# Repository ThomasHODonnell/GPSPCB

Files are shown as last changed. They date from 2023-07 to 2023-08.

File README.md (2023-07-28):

# GPS PCB - designing a consumer electronic from start to finish

## *Concepts*
- My father run a bicycle shop. Some of his customers' bicycles have been stolen. He asked me if I could design a product to help combat this problem. This problem led me to a GPS based solution - to get things started. 
- The solution provided here is an embedded system that can transmit its location upon request utilizing a satallite HTTP request API.
- This product combats the problem by not only locating a stolen / lost bicycle, but my locating a potential thief. Therefore, this product can act as a form of location verification for law enforcement bodies in pursuit of any item this PCB is attached to. 

## *Logistics* 
- I have designed 3D printed CAD models to safely secure this system on a moving bicycle. This system comfortably holds the PCB, its components and a battery. 
- While I have not completed suffient testing to determine the battery life of this system, its power consumption is very low for a reasonably sized battery and its capacity. This combination should ensure that the device does not need to be recharged for a reasonable amount of time. 

## Technical Information
- This initial design is intended to be minimalistic. I have foregone a Microcontroller Unit in an effort to minimize power consumption, size, and cost. Alternativly, I have implemented a standalone Reciever / Transciever combination to complete the necessary funcitonality without any additional computing. 
- Of course, there are a number of other ICs to accompany these functional components, such as LDO Regulators, Operational Amplifiers, Logic Gates, Switches, Battery IC, Low Noise Amplifier, and Antennas.  
- While this Electronic Circuit requires significantly more testing, the technical aspectrs of this solution offer a helpful initial solution to a logicically challenging problem. 

## Disclaimer
- I am a third-year Computer Engineering Student. In no fashion am I qualified to develop professional grade products at this point in my career. 
- Therefore, I would not recommend using any of my design choices for other applications without inquiring a professional. 
- I will post other README files within other folders with other information, screenshots, and files.

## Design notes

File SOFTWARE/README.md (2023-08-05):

# Software Information
 
## JSON

- The files found in this folder contain outline templates provided by STM for a JSON request and response. 
- These files have yet to be filled with server / device information. 
- Firmware will be developed to transmit / recieve these files.

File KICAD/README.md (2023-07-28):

# Kicad Files

## *This folder contains files needed to open / edit this project in KICAD.* 

- I'll use these files to provide screenshots from the IMAGES folder for your entertainment!
- This file could also be considered as a BOM, but i'll leave out component prices as they fluctuate frequently. 
- The PCB should be finished with production within the next week or so (7/27/23), after which I will upload real images of the device.

### **Electrical Schematics** 

#### Complete Schematic
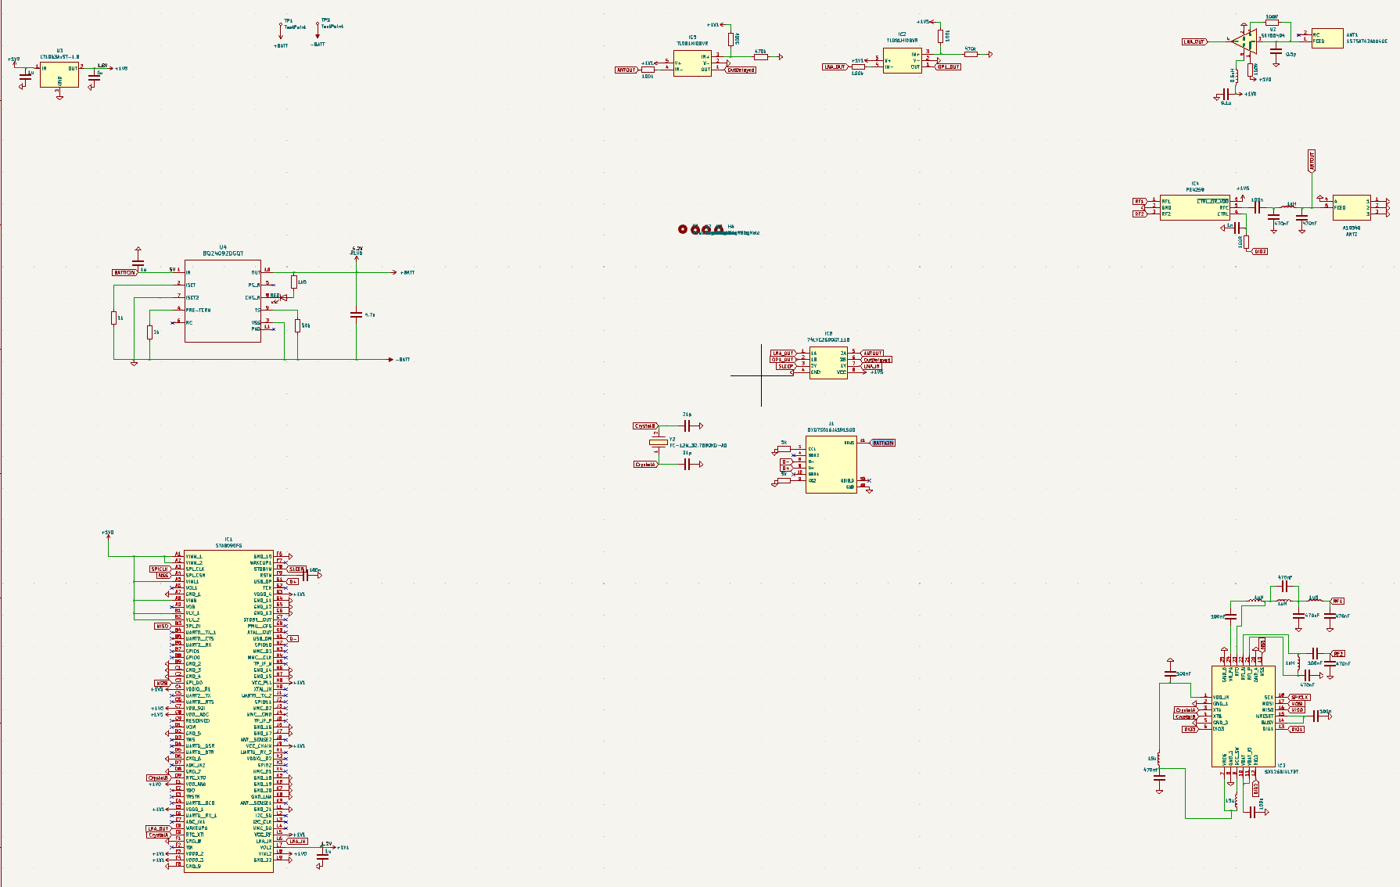
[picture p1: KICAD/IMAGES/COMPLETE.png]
Complete Schematic


#### LDO and Battery IC
- LDO(1.8V): LT1963A - Linear Technology
-  Rechargable Battert IC: BQ24092 - T.I.
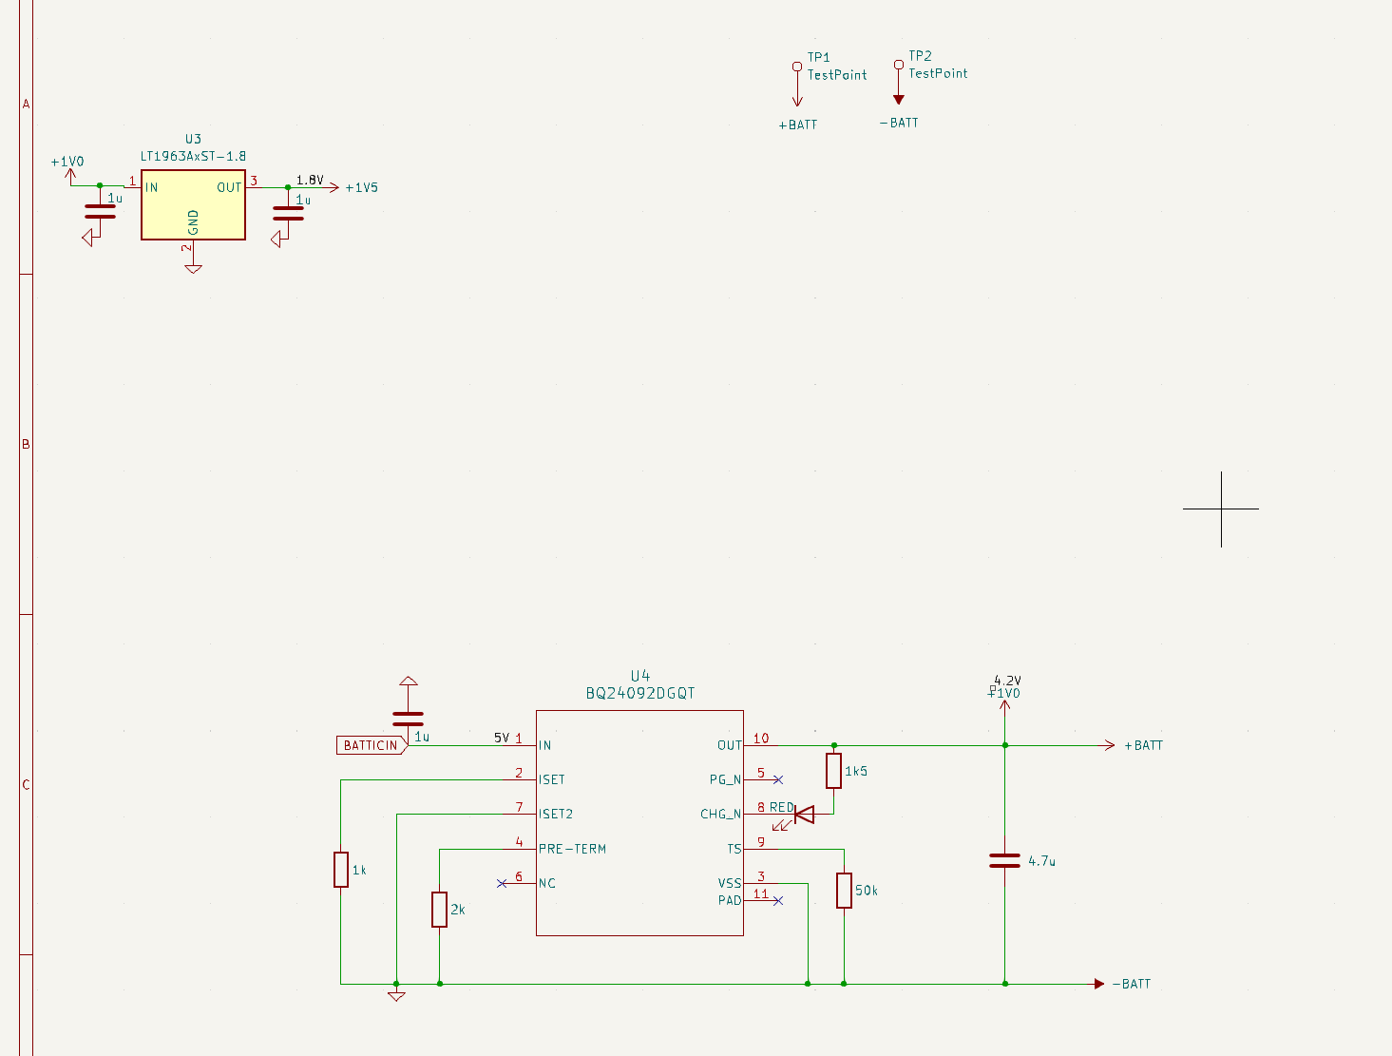
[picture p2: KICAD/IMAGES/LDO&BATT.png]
LDO + BATT ICS


#### Reciever
- RF Reciever: STA8090FG - STM32MicroElectronics
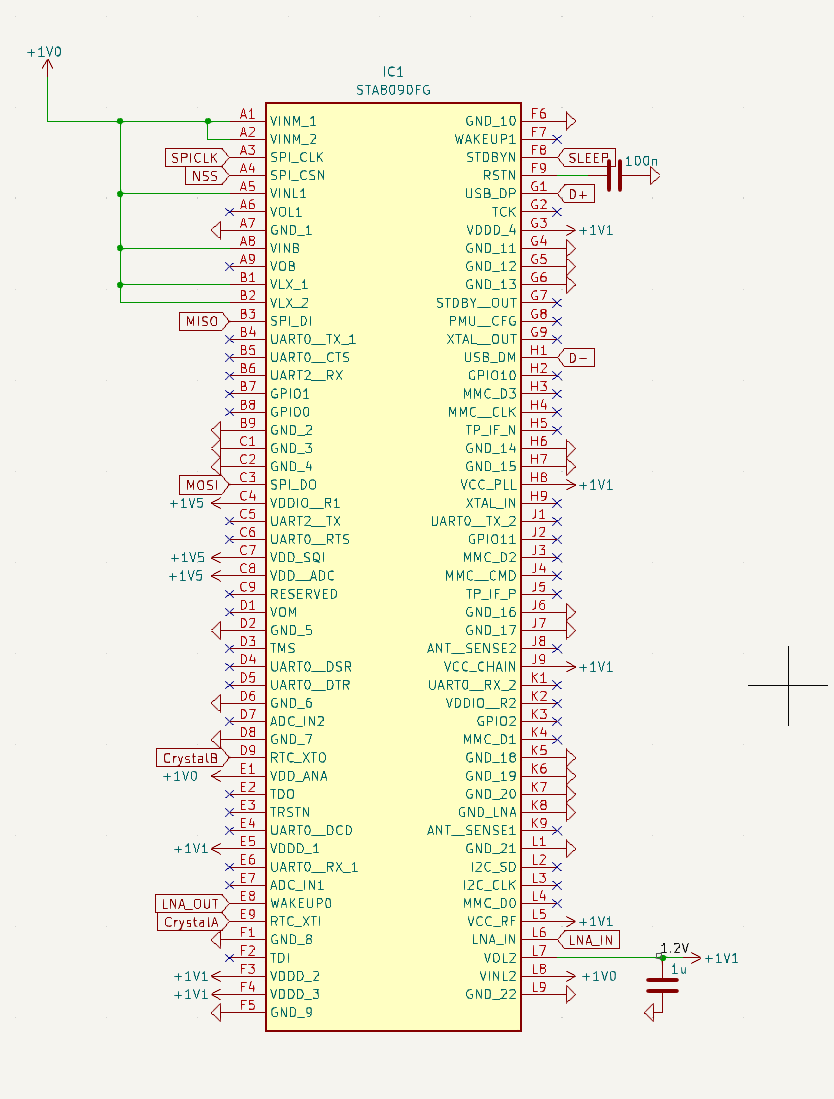
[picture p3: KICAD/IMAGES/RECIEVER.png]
RECIEVER
- 

#### Transciever
- RF signal transciever: SX1268IMLTRT - Semtech Corp. 
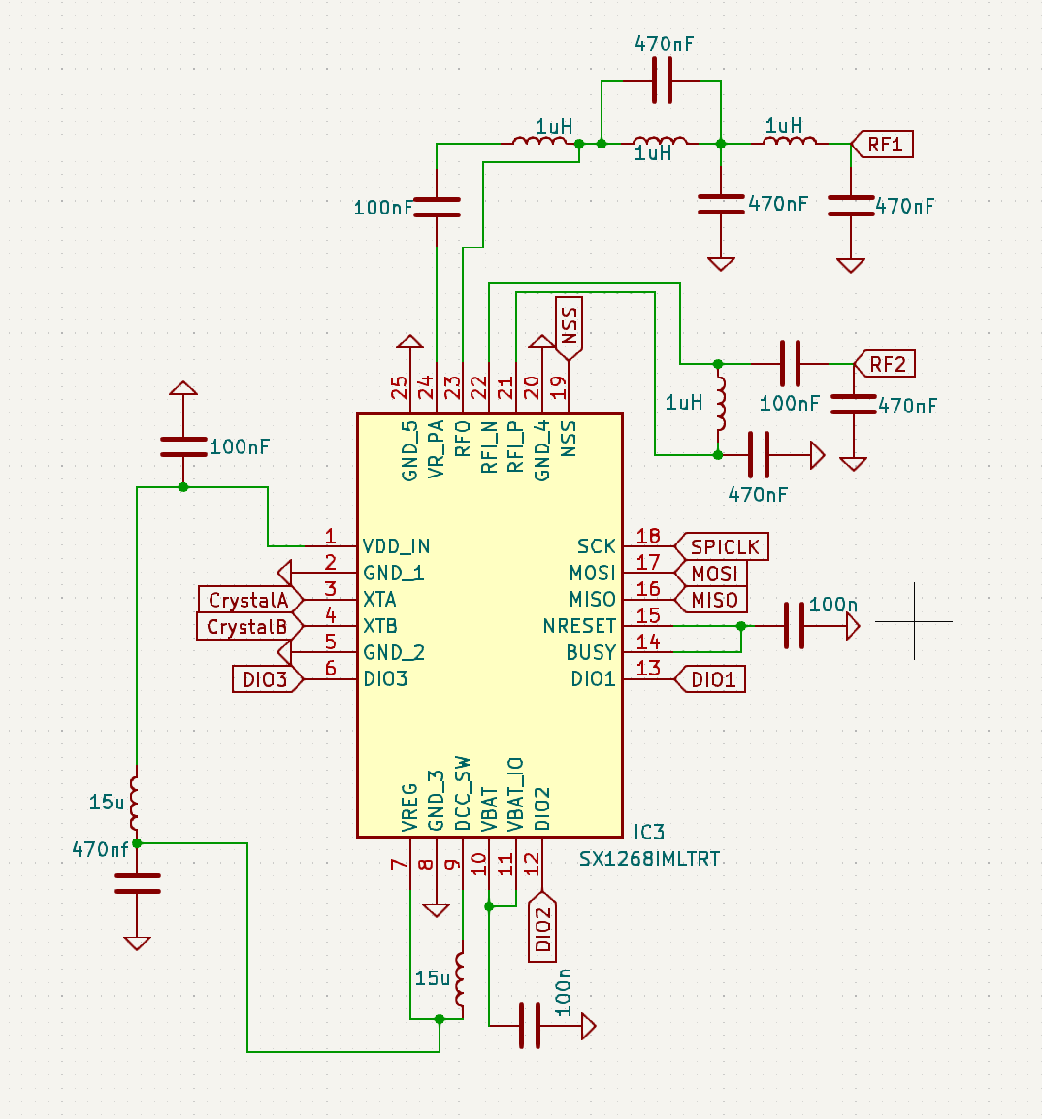
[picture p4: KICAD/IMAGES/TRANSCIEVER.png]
TRANSCIEVER


#### Various Components
- Op-Amp: TL081HIDBVR - T.I.
- LNA: SKY65404-31 - Skyworks
- Input Antenna: 1575AT43A0040001E - Johanson
- SPDT RF Switch: PE4259 - Pasternack
- Output Antenna: A10340 - Antenova
- Dual NAND Gate: 74LVC2G00GT,115 - Nexperia
- Water Resistant USBC Port: DX07S016JA1R1500 - JAE Elec. 
- 32 MHZ Crystal: FC-12M 32.7680KD-A0 - EPSON

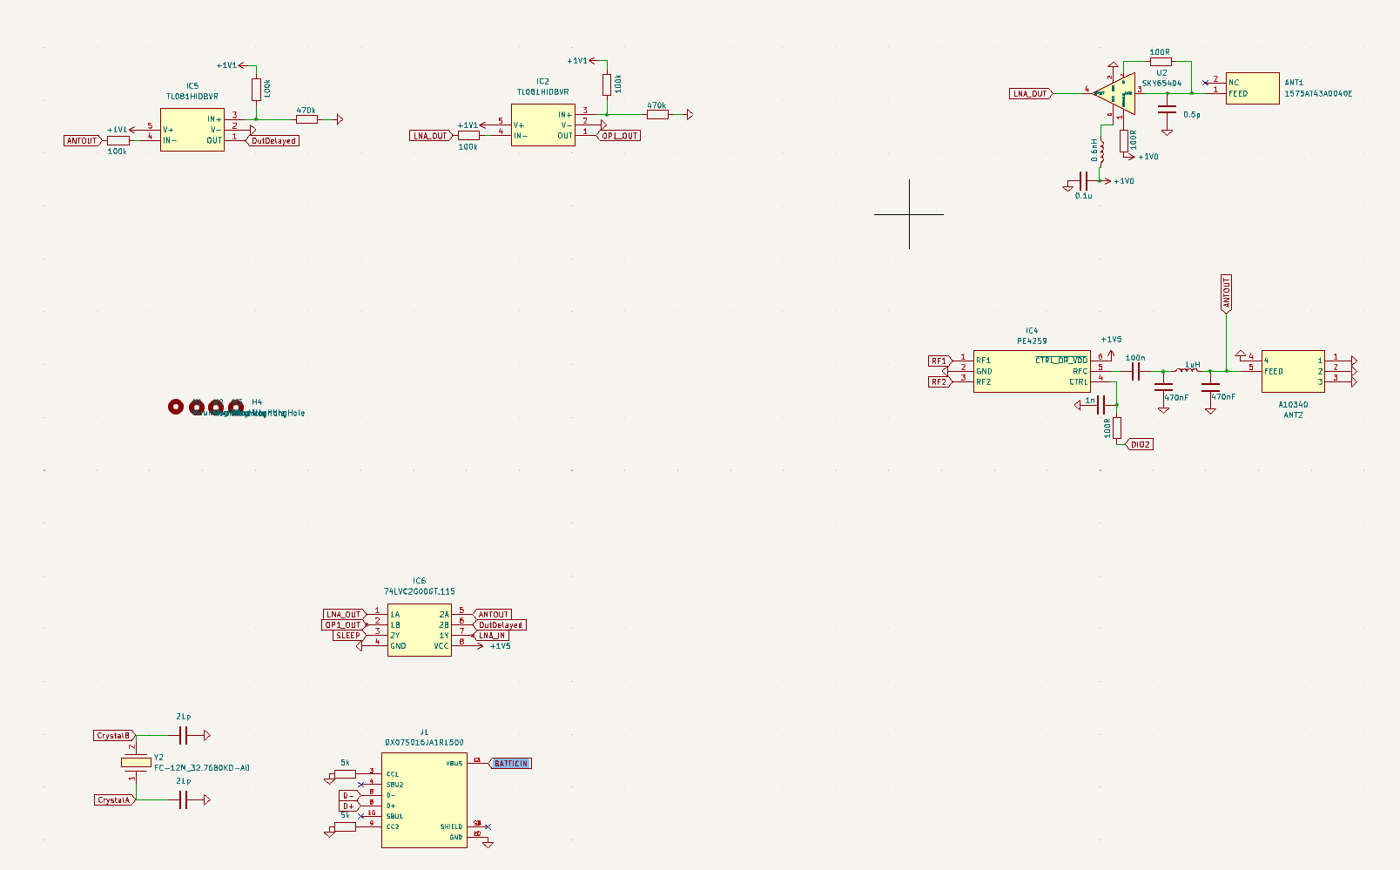
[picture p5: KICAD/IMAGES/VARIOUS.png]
VARIOUS


### **PCB Schematics**
- I will only show a screenshot of the Front Copper layer, as all of the components are located on this layer. 
- If interested, I welcome a detailed review of the PCB design through the direct file found in this folder. 
- DISCLAIMER: I AM NOT EMPLOYED BY PROTECTION AUTOMATED. I am interested in entrepreneurship in the future. 
If testing proves that a version of this product could become viable, I wanted to label the project as that businesses prototype. 

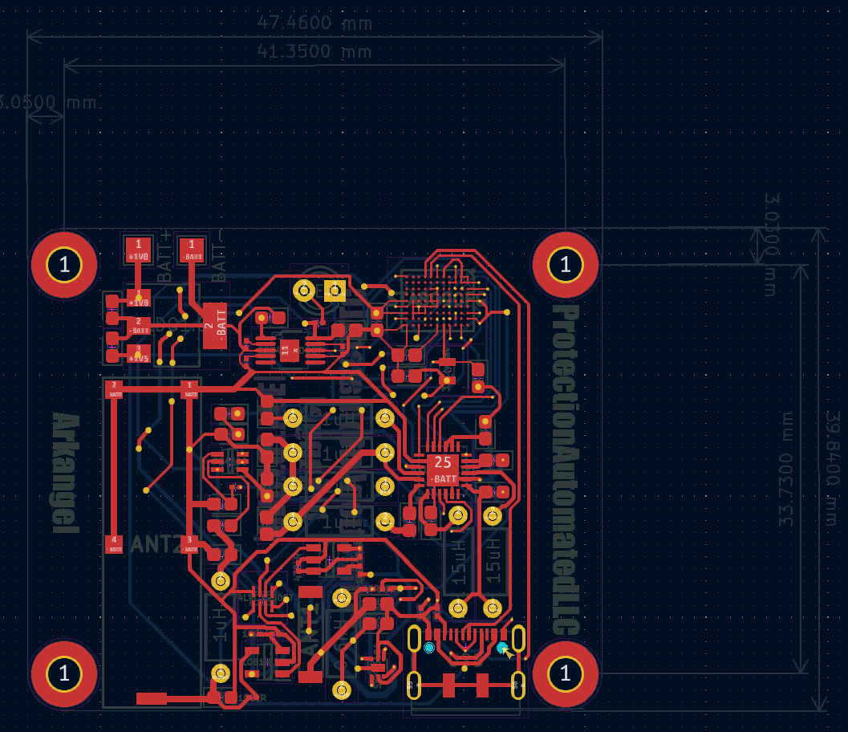
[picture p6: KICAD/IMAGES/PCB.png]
Front Copper Layer


- A 3D view for a more clear image. 

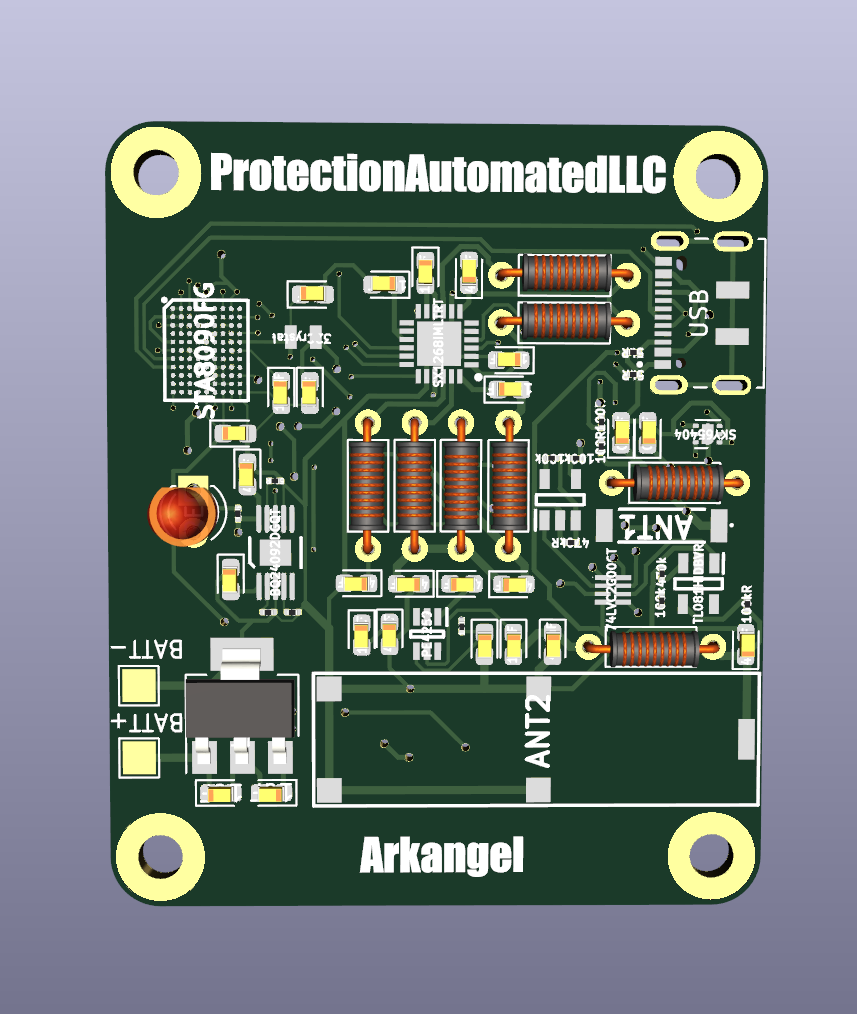
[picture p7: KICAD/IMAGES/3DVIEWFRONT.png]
Front 3D View

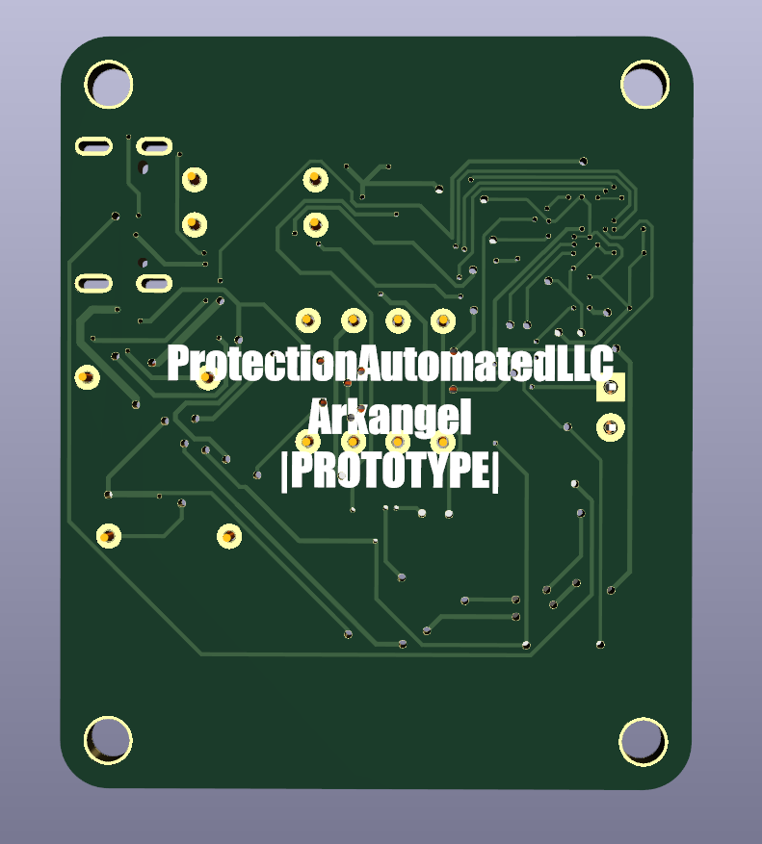
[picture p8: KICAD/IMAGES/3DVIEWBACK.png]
Rear 3D View


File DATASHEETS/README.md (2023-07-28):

# Datasheets 

- This file contains all of the datasheets for components in this file. 
- I based the vast majority of my design decisions on information found in these files. 
- In addition, there may be datasheets of additional parts not used in the design. 
  - When facing the component selection stage, I downloaded component datasheets that I suspected may be of use to me. 
  - Not all of these components are used, but I found their datasheets to provide helpful context information for similar parts I used. 
  - So, I kept them here for future reference.

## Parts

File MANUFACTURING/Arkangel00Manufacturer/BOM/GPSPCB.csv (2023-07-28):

Id | Designator | Footprint | Quantity | Designation | Supplier and ref
1 | C11,C15,C6,C11,C7 | CP_EIA-1608-08_AVX-J | 5 | 1u
2 | C21,C19,C25,C13,C20,C26,C23 | CP_EIA-1608-08_AVX-J | 7 | 470nF
3 | R9,R14,R15,R11 | R_0201_0603Metric | 4 | 100k
4 | C22,C18,C16 | CP_EIA-1608-08_AVX-J | 3 | 100nF
5 | C24,C12 | CP_EIA-1608-08_AVX-J | 2 | 100n
6 | C10,C10 | CP_EIA-1608-08_AVX-J | 2 | 4.7u
7 | H2,H1,H4,H3 | MountingHole_2.1mm | 4 | MountingHole
8 | ANT1 | 1575AT43A0040E | 1 | 1575AT43A0040E
9 | L5,L2,L7,L8,L6 | L_Axial_L5.3mm_D2.2mm_P7.62mm_Horizontal_Vishay_IM-1 | 5 | 1uH
10 | U3 | SOT-223-3_TabPin2 | 1 | LT1963AxST-1.8
11 | R2,R8 | R_0201_0603Metric | 2 | 5k
12 | R6 | R_0201_0603Metric | 1 | 50k
13 | R16,R10 | R_0201_0603Metric | 2 | 470k
14 | R1,R3,R12 | R_0201_0603Metric | 3 | 100R
15 | C14 | CP_EIA-1608-08_AVX-J | 1 | 470nf
16 | D2 | LED_D3.0mm | 1 | RED
17 | C4,C5 | CP_EIA-1608-08_AVX-J | 2 | 21p
18 | L3,L4 | L_Axial_L5.3mm_D2.2mm_P7.62mm_Horizontal_Vishay_IM-1 | 2 | 15uH
19 | C9,C9 | CP_EIA-1608-08_AVX-J | 2 | 0.5p
20 | C27 | CP_EIA-1608-08_AVX-J | 1 | 1n
21 | R4 | R_0201_0603Metric | 1 | 1k
22 | U2 | Skyworks_SKY65404-31 | 1 | SKY65404
23 | IC6 | 74AVC9112GTX | 1 | 74LVC2G00
24 | IC5,IC2 | SOT95P280X145-5N | 2 | TL081HIDBVR
25 | ANT2 | A10340 | 1 | A10340
26 | IC3 | QFN50P400X400X100-25N-D | 1 | SX1268
27 | J1 | JAE_DX07S016JA1R1500 | 1 | DX07S016JA1R1500
28 | C8,C8 | CP_EIA-1608-08_AVX-J | 2 | 0.1u
29 | TP | TestPoint_Pad_2.0x2.0mm | 1 | BATT+
30 | C1,C17 | CP_EIA-1608-08_AVX-J | 2 | 100nf
31 | Y2 | FC12M327680KDA0 | 1 | Crystal
32 | TP2 | TestPoint_Pad_2.0x2.0mm | 1 | BATT-
33 | R7 | R_0201_0603Metric | 1 | 1k5
34 | U4 | DGQ0010D_NV_N | 1 | BQ24092
35 | R5 | R_0201_0603Metric | 1 | 2k
36 | STA8090FG | BGA99C50P9X11_500X600X120 | 1 | STA8090FG
37 | IC4 | SOT65P210X110-6N | 1 | PE4259
38 | L1 | L_Axial_L5.3mm_D2.2mm_P7.62mm_Horizontal_Vishay_IM-1 | 1 | 0.6nH

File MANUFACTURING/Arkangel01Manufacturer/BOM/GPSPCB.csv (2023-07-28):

Id | Designator | Footprint | Quantity | Designation | Supplier and ref
1 | C14,C19,C23,C21,C25,C13,C26,C20 | CP_EIA-1608-08_AVX-J | 8 | 470nF
2 | C9 | CP_EIA-1608-08_AVX-J | 1 | 0.5pF
3 | R5 | R_0201_0603Metric | 1 | 2k
4 | L3,L4 | L_Axial_L5.3mm_D2.2mm_P7.62mm_Horizontal_Vishay_IM-1 | 2 | 15uH
5 | C18,C16,C12,C22,C24,Ce,C17 | CP_EIA-1608-08_AVX-J | 7 | 100nF
6 | C15,C6,C7,C11 | CP_EIA-1608-08_AVX-J | 4 | 1uF
7 | D2 | LED_D3.0mm | 1 | RED
8 | R14 | R_0201_0603Metric | 1 | 100kR
9 | H4,H2,H3,H1 | MountingHole_2.7mm_M2.5_Pad_TopOnly | 4 | MountingHole
10 | C4,C5 | CP_EIA-1608-08_AVX-J | 2 | 21pF
11 | J1 | JAE_DX07S016JA1R1500 | 1 | USB
12 | L2,Le,L7,L8,L5 | L_Axial_L5.3mm_D2.2mm_P7.62mm_Horizontal_Vishay_IM-1 | 5 | 1uH
13 | R9,R15,R11 | R_0201_0603Metric | 3 | 100k
14 | R4 | R_0201_0603Metric | 1 | 1k
15 | IC2,IC5 | SOT95P280X145-5N | 2 | TL081HIDBVR
16 | U4 | DGQ0010D_NV_N | 1 | BQ24092DGQT
17 | R7 | R_0201_0603Metric | 1 | 1k5
18 | IC4 | SOT65P210X110-6N | 1 | PE4259
19 | R6 | R_0201_0603Metric | 1 | 50kR
20 | TP2 | TestPoint_Pad_2.0x2.0mm | 1 | BATT-
21 | Y2 | FC12M327680KDA0 | 1 | 32Crystal
22 | ANT1 | 1575AT43A0040E | 1 | 1575AT43A0040E
23 | L1 | L_Axial_L5.3mm_D2.2mm_P7.62mm_Horizontal_Vishay_IM-1 | 1 | 0.6nH
24 | R16 | R_0201_0603Metric | 1 | 470k
25 | R10 | R_0201_0603Metric | 1 | 470kR
26 | ANT2 | A10340 | 1 | A10340
27 | R2,R8 | R_0201_0603Metric | 2 | 5kR
28 | U2 | Skyworks_SKY65404-31 | 1 | SKY65404
29 | C8 | CP_EIA-1608-08_AVX-J | 1 | 0.1uF
30 | U3 | SOT-223-3_TabPin2 | 1 | LDO1.8
31 | IC6 | 74AVC9112GTX | 1 | 74LVC2G00GT
32 | C10 | CP_EIA-1608-08_AVX-J | 1 | 4.7uF
33 | IC3 | QFN50P400X400X100-25N-D | 1 | SX1268IMLTRT
34 | IC1 | BGA99C50P9X11_500X600X120 | 1 | STA8090FG
35 | R3,R12,R1 | R_0201_0603Metric | 3 | 100R
36 | C27 | CP_EIA-1608-08_AVX-J | 1 | 1nF
37 | TP1 | TestPoint_Pad_2.0x2.0mm | 1 | BATT+

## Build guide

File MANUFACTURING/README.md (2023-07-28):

# Manufacturing Files

## *This folder contains all manufacturing files for both versions of this PCB.*
These files were sent directly to the manufacturer and can be viewed through Kicad's GERBER VIEWER software.

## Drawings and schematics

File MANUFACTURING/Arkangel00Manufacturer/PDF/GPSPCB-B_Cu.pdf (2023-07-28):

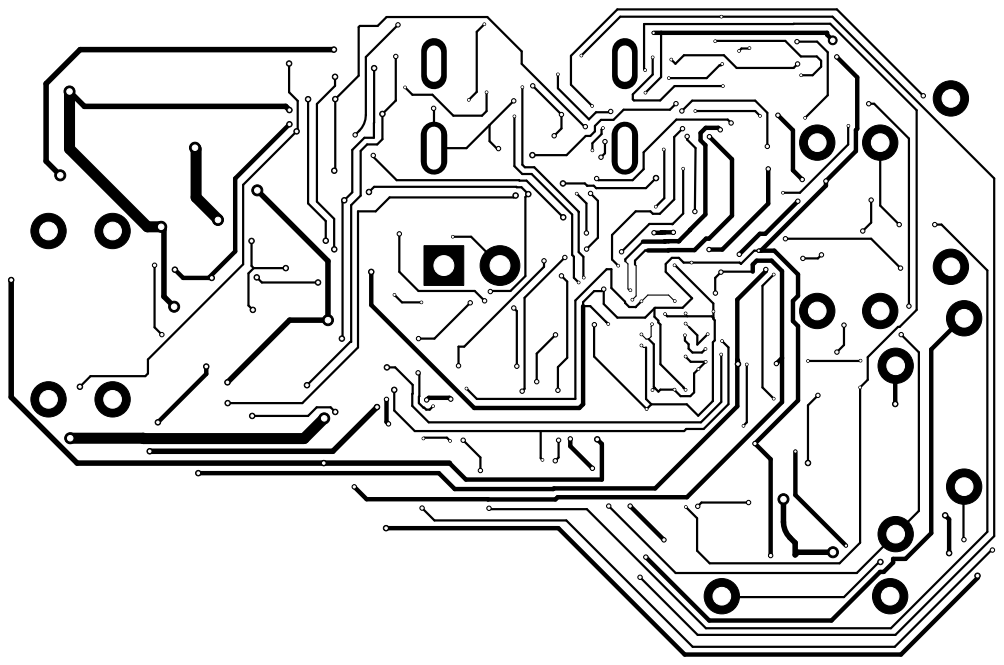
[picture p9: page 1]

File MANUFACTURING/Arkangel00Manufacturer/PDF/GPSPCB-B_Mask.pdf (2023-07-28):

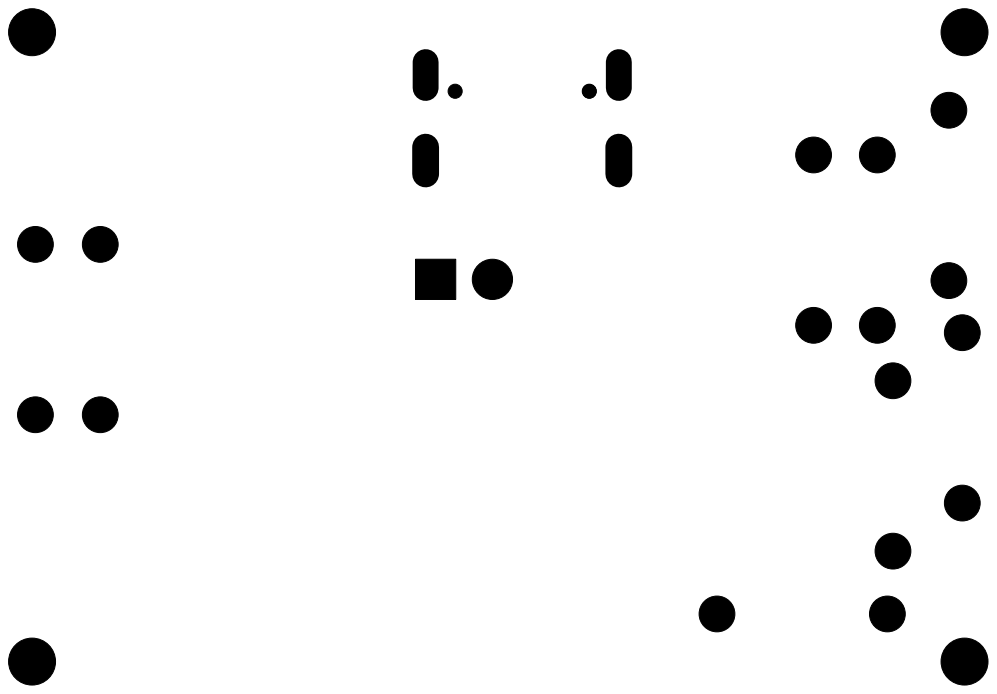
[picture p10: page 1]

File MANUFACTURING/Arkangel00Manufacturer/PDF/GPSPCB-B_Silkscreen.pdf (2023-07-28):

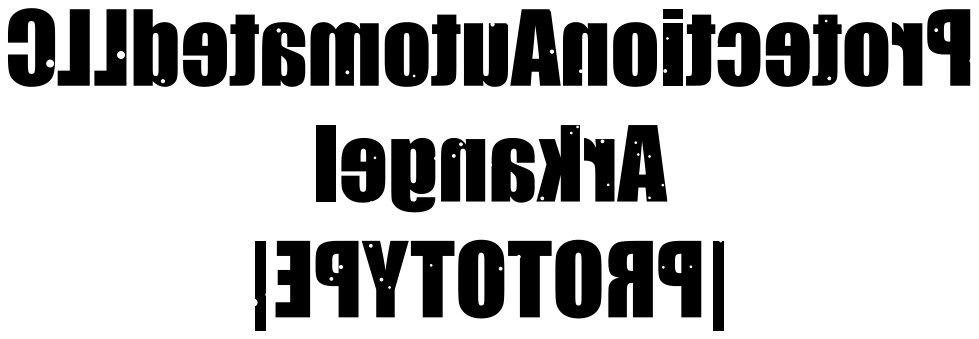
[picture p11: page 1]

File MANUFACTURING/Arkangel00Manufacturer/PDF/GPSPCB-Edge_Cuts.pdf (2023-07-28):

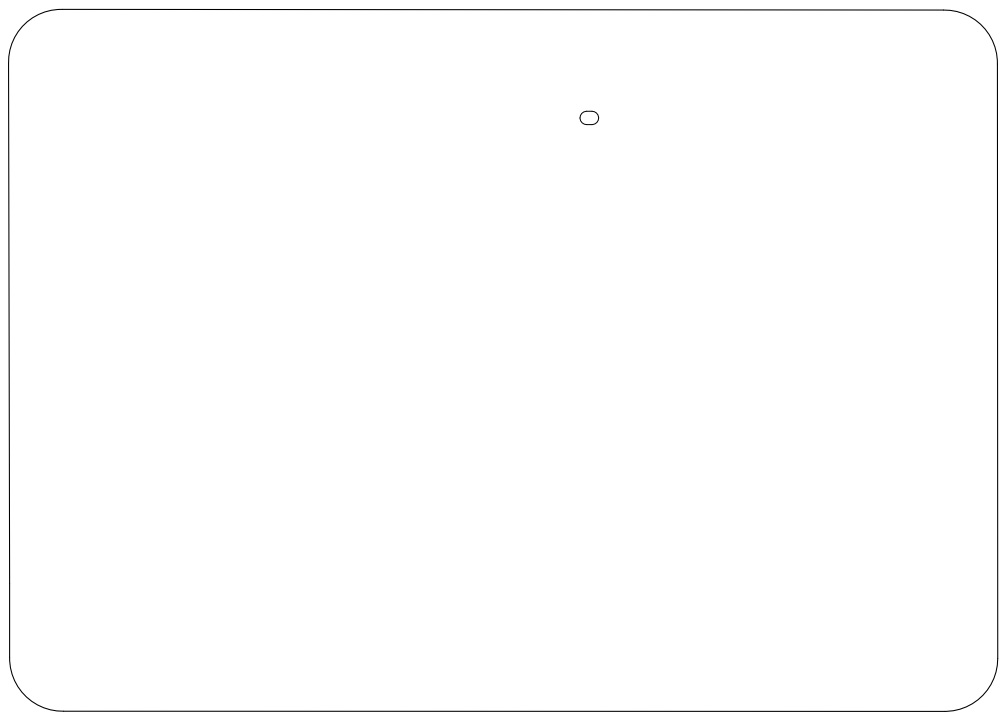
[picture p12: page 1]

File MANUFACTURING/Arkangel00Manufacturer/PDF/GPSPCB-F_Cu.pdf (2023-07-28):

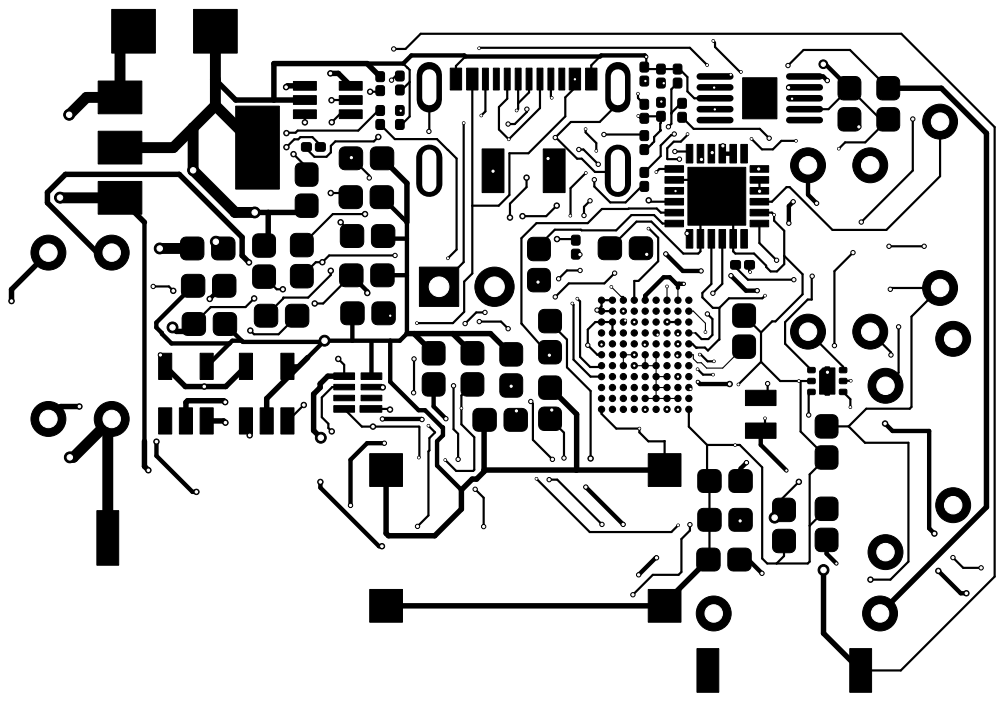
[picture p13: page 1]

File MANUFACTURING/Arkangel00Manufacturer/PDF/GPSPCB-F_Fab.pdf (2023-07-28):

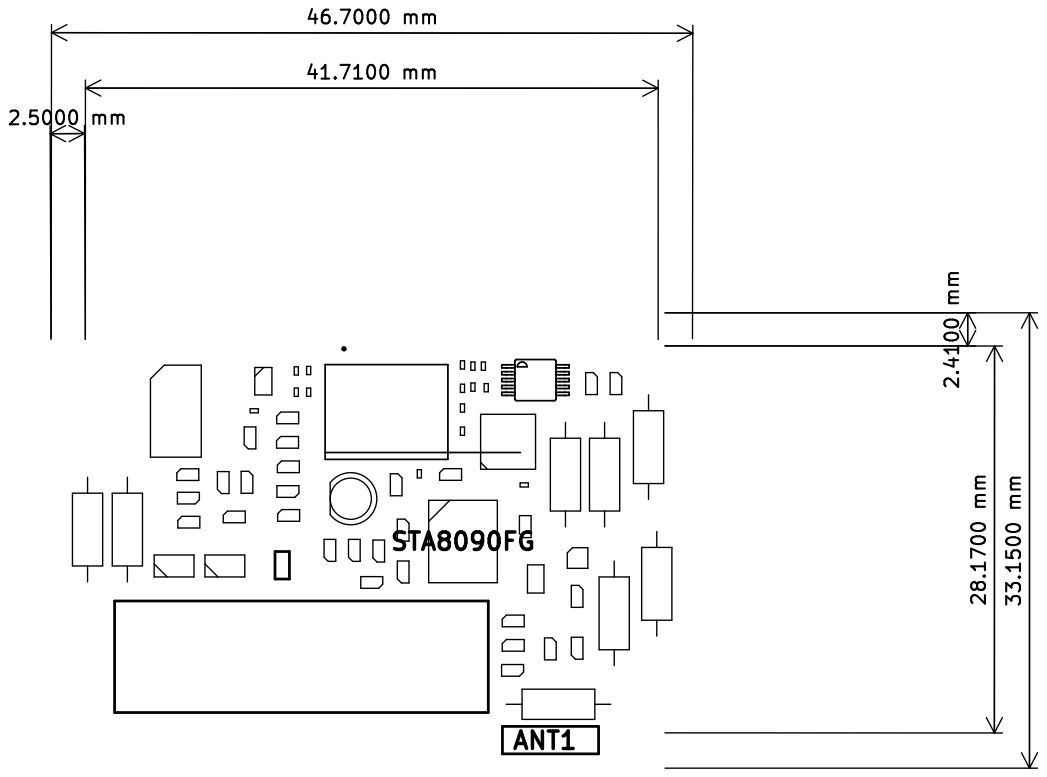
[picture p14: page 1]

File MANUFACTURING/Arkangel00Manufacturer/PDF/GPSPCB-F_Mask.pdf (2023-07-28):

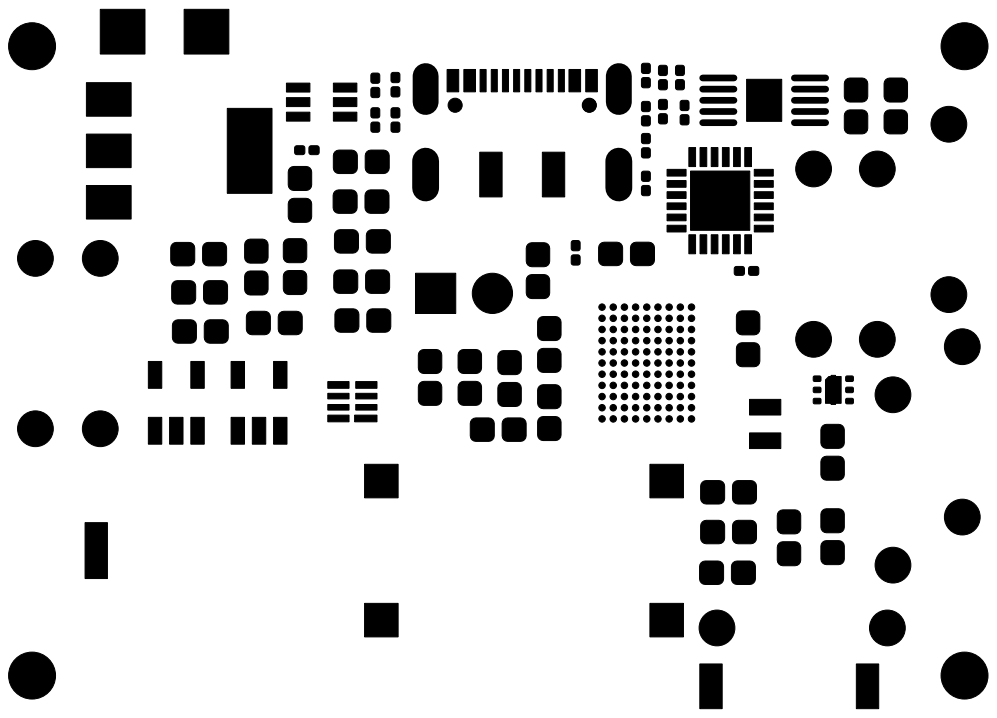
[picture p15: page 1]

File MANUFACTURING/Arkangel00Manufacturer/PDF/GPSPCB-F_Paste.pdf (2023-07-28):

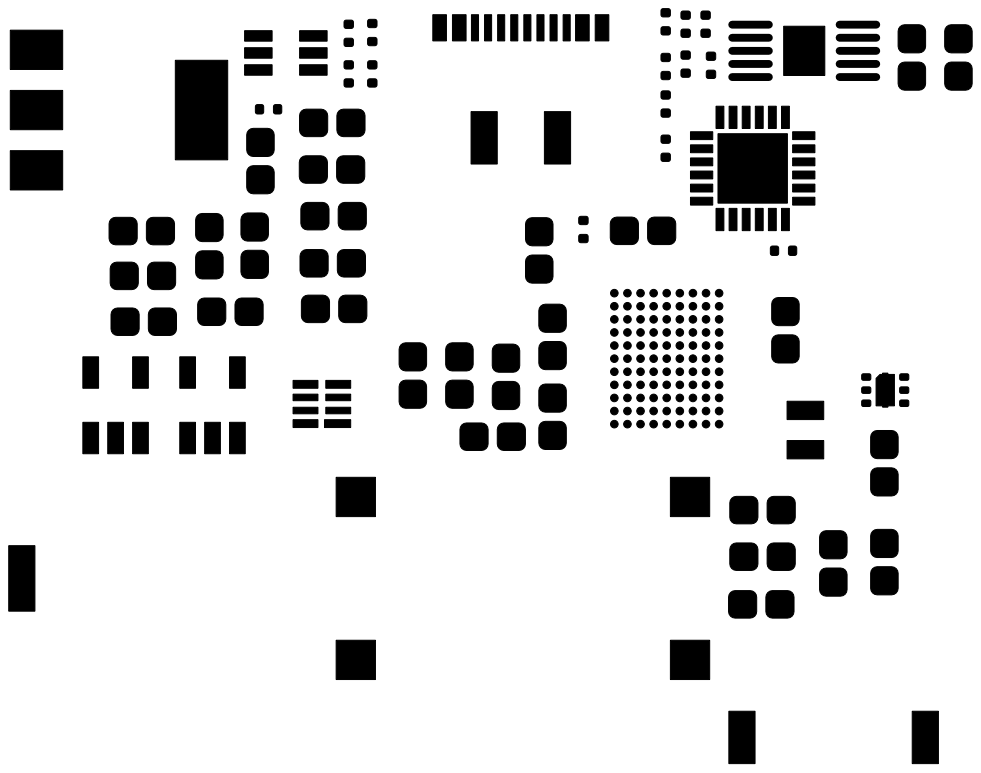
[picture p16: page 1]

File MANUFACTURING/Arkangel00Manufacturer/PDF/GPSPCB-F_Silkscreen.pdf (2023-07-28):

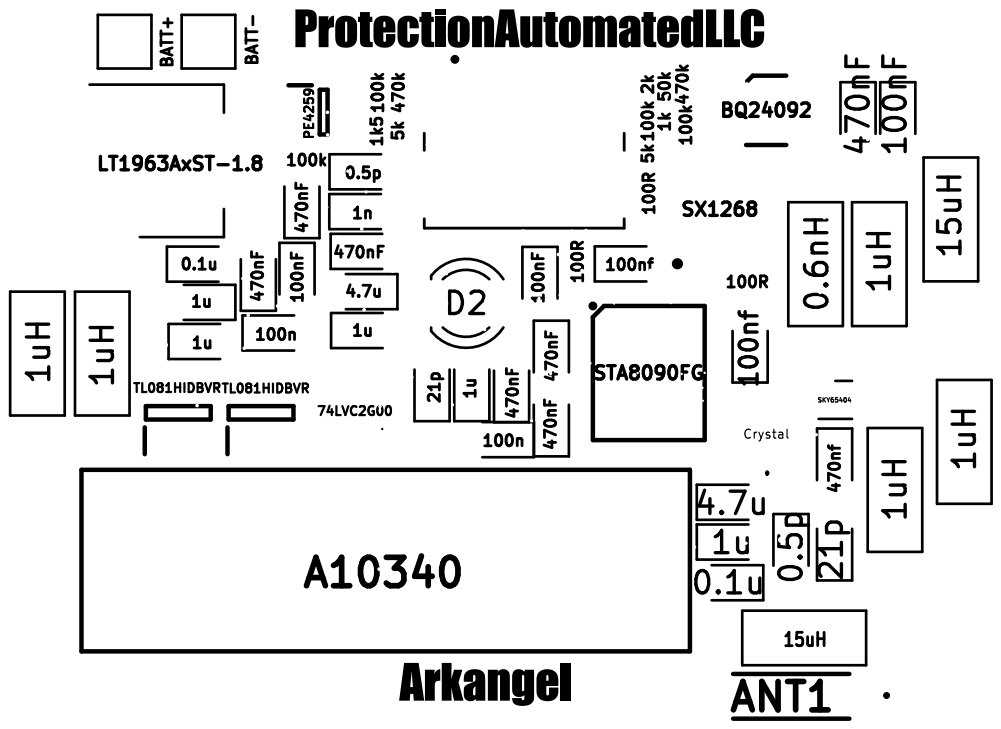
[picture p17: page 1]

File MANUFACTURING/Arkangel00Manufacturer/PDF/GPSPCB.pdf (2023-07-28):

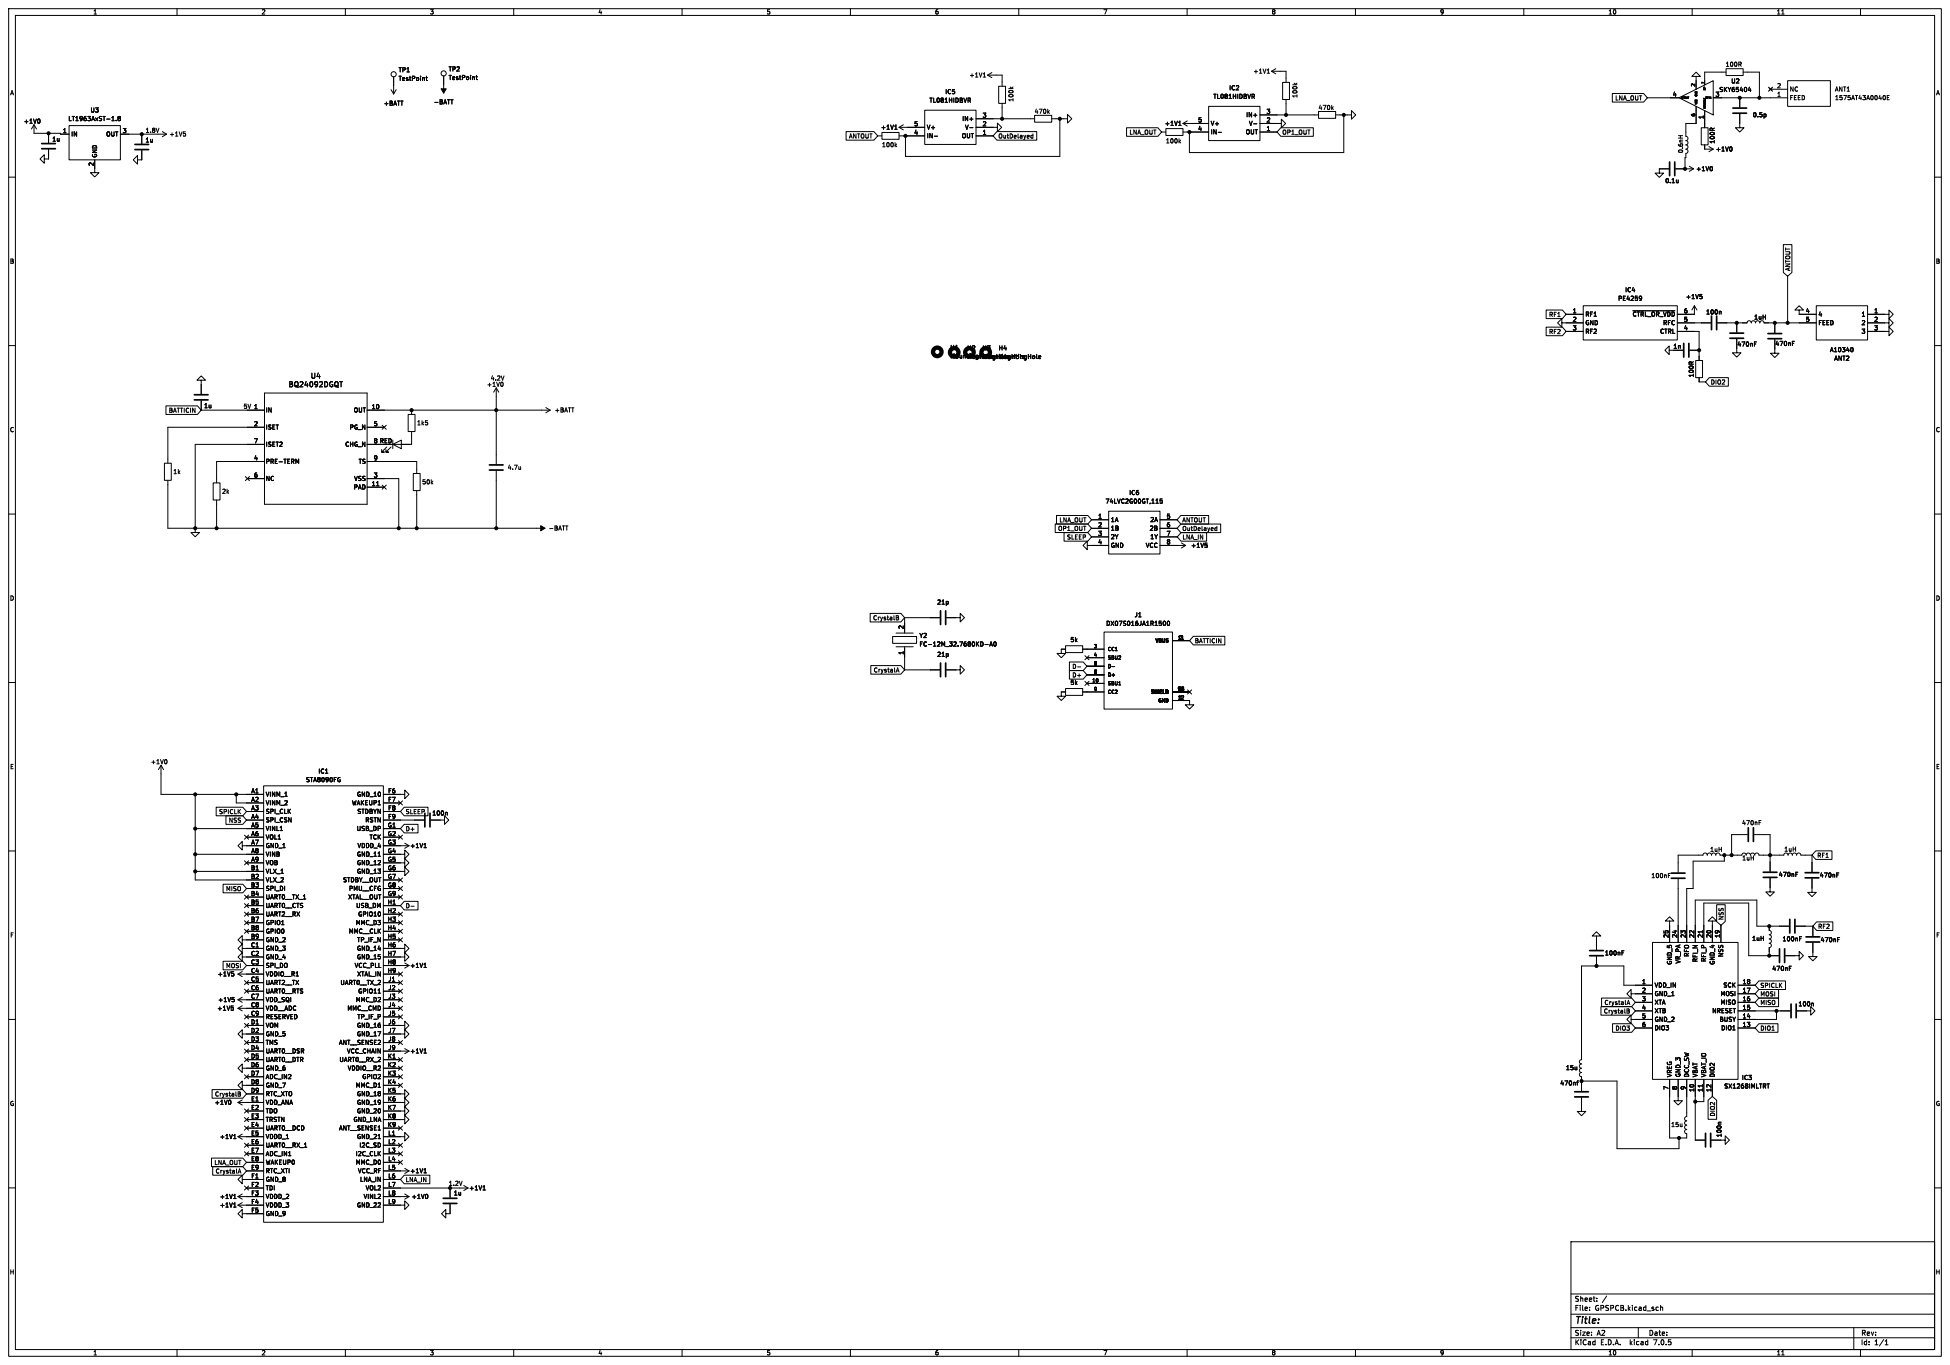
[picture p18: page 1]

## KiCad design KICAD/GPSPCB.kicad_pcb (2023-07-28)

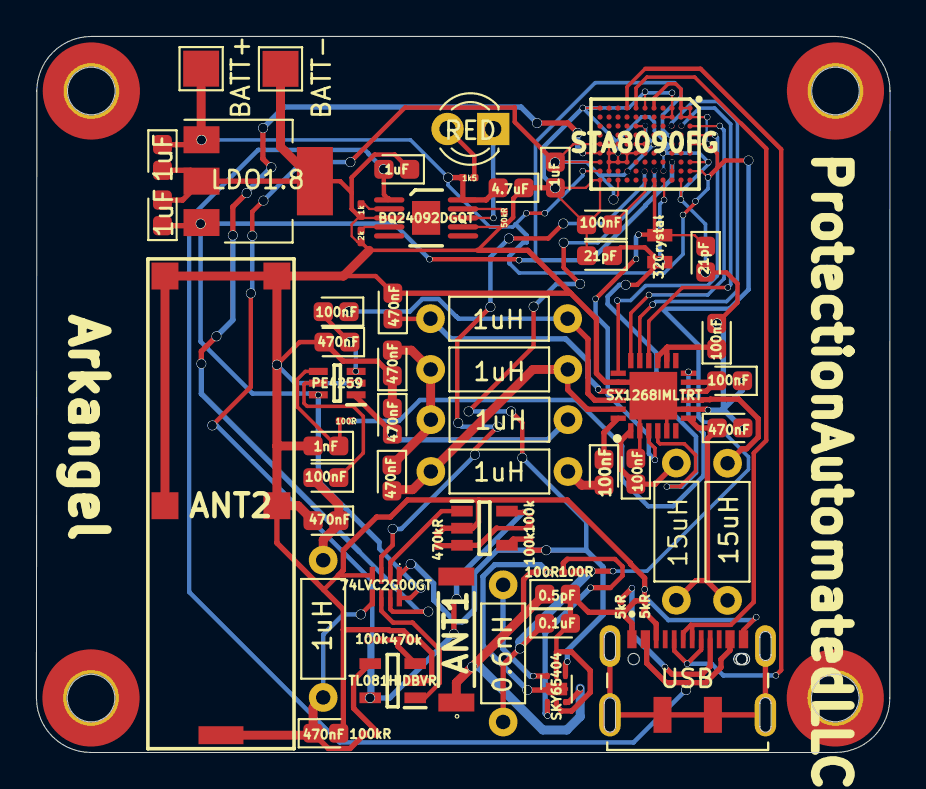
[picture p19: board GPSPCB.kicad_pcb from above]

Board: 2 copper layers, 47.4 x 39.8 mm, 68 parts (0 on the bottom side), 52 nets.

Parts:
ANT1: 1575AT43A0040E
ANT2: A10340
C4, C5: 21pF; CP_EIA-1608-08_AVX-J
C6, C7, C11, C15: 1uF; CP_EIA-1608-08_AVX-J
C8: 0.1uF; CP_EIA-1608-08_AVX-J
C9: 0.5pF; CP_EIA-1608-08_AVX-J
C10: 4.7uF; CP_EIA-1608-08_AVX-J
C12, C16, C17, C18, C22, C24: 100nF; CP_EIA-1608-08_AVX-J
C13, C14, C19, C20, C21, C23, C25, C26: 470nF; CP_EIA-1608-08_AVX-J
C27: 1nF; CP_EIA-1608-08_AVX-J
Ce: 100nF; CP_EIA-1608-08_AVX-J
D2: RED; LED_D3.0mm
H1, H2, H3, H4: MountingHole; MountingHole_2.7mm_M2.5_Pad_TopOnly
IC1: STA8090FG; BGA99C50P9X11_500X600X120
IC2, IC5: TL081HIDBVR; SOT95P280X145-5N
IC3: SX1268IMLTRT; QFN50P400X400X100-25N-D
IC4: PE4259; SOT65P210X110-6N
IC6: 74LVC2G00GT; 74AVC9112GTX
J1: USB; JAE_DX07S016JA1R1500
L1: 0.6nH; L_Axial_L5.3mm_D2.2mm_P7.62mm_Horizontal_Vishay_IM-1
L2, L5, L7, L8: 1uH; L_Axial_L5.3mm_D2.2mm_P7.62mm_Horizontal_Vishay_IM-1
L3, L4: 15uH; L_Axial_L5.3mm_D2.2mm_P7.62mm_Horizontal_Vishay_IM-1
Le: 1uH; L_Axial_L5.3mm_D2.2mm_P7.62mm_Horizontal_Vishay_IM-1
R1, R3, R12: 100R; R_0201_0603Metric
R2, R8: 5kR; R_0201_0603Metric
R4: 1k; R_0201_0603Metric
R5: 2k; R_0201_0603Metric
R6: 50kR; R_0201_0603Metric
R7: 1k5; R_0201_0603Metric
R9, R11, R15: 100k; R_0201_0603Metric
R10: 470kR; R_0201_0603Metric
R14: 100kR; R_0201_0603Metric
R16: 470k; R_0201_0603Metric
TP1: BATT+; TestPoint_Pad_2.0x2.0mm
TP2: BATT-; TestPoint_Pad_2.0x2.0mm
U2: SKY65404; Skyworks_SKY65404-31
U3: LDO1.8; SOT-223-3_TabPin2
U4: BQ24092DGQT; DGQ0010D_NV_N
Y2: 32Crystal; FC12M327680KDA0

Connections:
+1V0: C6.1, C8.1, C10.2, IC1.A1 (VINM_1), IC1.A2 (VINM_2), IC1.A5 (VINL1), IC1.A8 (VINB), IC1.B1 (VLX_1), IC1.B2 (VLX_2), IC1.E1 (VDD_ANA), IC1.L8 (VINL2), L1.2, R3.2, R7.1, TP1.1, U3.1 (IN), U4.10 (OUT)
+1V1: C15.1, IC1.E5 (VDDD_1), IC1.F3 (VDDD_2), IC1.F4 (VDDD_3), IC1.G3 (VDDD_4), IC1.H8 (VCC_PLL), IC1.J9 (VCC_CHAIN), IC1.L5 (VCC_RF), IC1.L7 (VOL2), IC2.5 (V+), IC5.5 (V+), R9.1, R15.1
+1V5: C7.1, IC1.C4 (VDDIO__R1), IC1.C7 (VDD_SQI), IC1.C8 (VDD__ADC), IC4.6 (~CTRL_OR_VDD), IC6.8 (VCC), U3.3 (OUT)
-BATT: ANT2.1, ANT2.2, ANT2.3, ANT2.4, C4.2, C5.2, C6.2, C7.2, C8.2, C9.2, C10.1, C11.1, C12.2, C14.2, C15.2, C17.1, C18.2, C19.1, C20.1, C21.2, C23.2, C25.2, C26.2, C27.2, Ce.2, IC1.A7 (GND_1), IC1.B9 (GND_2), IC1.C1 (GND_3), IC1.C2 (GND_4), IC1.D2 (GND_5), IC1.D6 (GND_6), IC1.D8 (GND_7), IC1.F1 (GND_8), IC1.F5 (GND_9), IC1.F6 (GND_10), IC1.G4 (GND_11), IC1.G5 (GND_12), IC1.G6 (GND_13), IC1.H6 (GND_14), IC1.H7 (GND_15), IC1.J6 (GND_16), IC1.J7 (GND_17), IC1.K5 (GND_18), IC1.K6 (GND_19), IC1.K7 (GND_20), IC1.K8 (GND_LNA), IC1.L1 (GND_21), IC1.L9 (GND_22), IC2.2 (V-), IC3.2 (GND_1), IC3.5 (GND_2), IC3.8 (GND_3), IC3.20 (GND_4), IC3.25 (GND_5), IC4.2 (GND), IC5.2 (V-), IC6.4 (GND), J1.1 (GND), J1.12 (GND), R2.1, R4.2, R5.2, R6.2, R8.1, R10.2, R16.2, TP2.1, U2.2 (GND), U2.5 (GND), U3.2 (GND), U4.3 (VSS), U4.7 (ISET2)
ANTOUT: ANT2.5 (FEED), C26.1, IC6.5 (2A), L8.1, R14.1
BATTICIN: C11.2, J1.2 (VBUS), J1.11 (VBUS), U4.1 (IN)
CrystalA: C5.1, IC1.E9 (RTC_XTI), IC3.3 (XTA), Y2.1
CrystalB: C4.1, IC1.D9 (RTC_XTO), IC3.4 (XTB), Y2.2
D+: IC1.G1 (USB_DP), J1.6 (D+), J1.7 (D+)
D-: IC1.H1 (USB_DM), J1.5 (D-), J1.8 (D-)
DIO2: IC3.12 (DIO2), R12.2
LNA_IN: IC1.L6 (LNA_IN), IC6.7 (1Y)
LNA_OUT: IC1.E8 (WAKEUP0), IC6.1 (1A), R11.1, U2.4 (RFOUT)
MISO: IC1.B3 (SPI_DI), IC3.16 (MISO)
MOSI: IC1.C3 (SPI_DO), IC3.17 (MOSI)
NSS: IC1.A4 (SPI_CSN), IC3.19 (NSS)
unnamed: ANT1.1 (FEED), C9.1, R1.2, U2.3 (RFIN)
unnamed: C13.1, C19.2, L5.1, Le.2
unnamed: C16.2, L2.2
unnamed: C24.2, C25.1, L8.2
unnamed: D2.2 (A), R7.2
unnamed: D2.1 (K), U4.8 (CHG_N)
unnamed: Ce.1, IC1.F9 (RSTN)
unnamed: IC2.3 (IN+), R9.2, R10.1
unnamed: IC2.4 (IN-), R11.2
unnamed: C12.1, IC3.14 (BUSY), IC3.15 (NRESET)
unnamed: IC3.9 (DCC_SW), L4.2
unnamed: C22.1, IC3.22 (RFI_N), L7.2
unnamed: C21.1, IC3.21 (RFI_P), L7.1
unnamed: C13.2, IC3.23 (RFO), L2.1, L5.2
unnamed: C17.2, IC3.10 (VBAT), IC3.11 (VBAT_IO)
unnamed: C18.1, IC3.1 (VDD_IN), L3.2
unnamed: C14.1, IC3.7 (VREG), L3.1, L4.1
unnamed: C16.1, IC3.24 (VR_PA)
unnamed: C27.1, IC4.4 (CTRL), R12.1
unnamed: C24.1, IC4.5 (RFC)
unnamed: IC5.3 (IN+), R15.2, R16.1
unnamed: IC5.4 (IN-), R14.2
unnamed: J1.3 (CC1), R8.2
unnamed: J1.9 (CC2), R2.2
unnamed: R1.1, U2.7 (EP)
unnamed: L1.1, U2.6 (VCC)
unnamed: R3.1, U2.1 (VENABLE)
unnamed: R4.1, U4.2 (ISET)
unnamed: R5.1, U4.4 (PRE-TERM)
unnamed: R6.1, U4.9 (TS)
OP1_OUT: IC2.1 (OUT), IC6.2 (1B)
OutDelayed: IC5.1 (OUT), IC6.6 (2B)
RF1: C20.2, IC4.1 (RF1), Le.1
RF2: C22.2, C23.1, IC4.3 (RF2)
SLEEP: IC1.F8 (STDBYN), IC6.3 (2Y)
SPICLK: IC1.A3 (SPI_CLK), IC3.18 (SCK)
